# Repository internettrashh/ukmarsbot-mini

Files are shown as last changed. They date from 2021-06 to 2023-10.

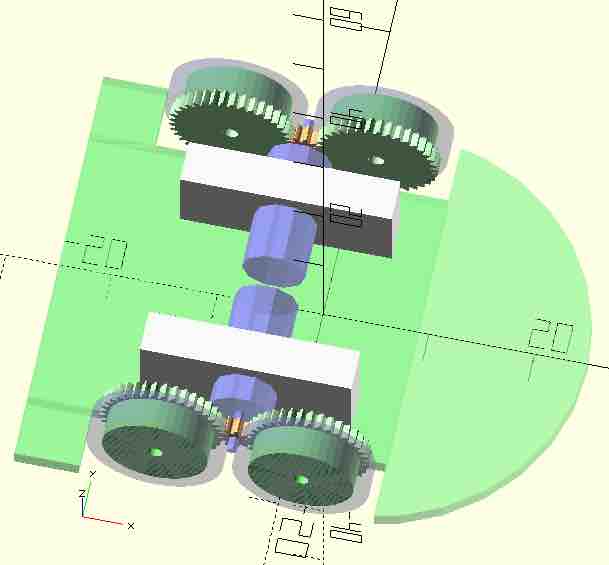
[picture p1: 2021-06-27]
half-size-mech-prototypes/prototype1.jpg

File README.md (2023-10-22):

# ukmarsbot-mini
A half size micromouse project

Over time, this will grow into a fully described project for an open source, half-sized micromouse designed by members of the UK Micromouse and Robotics Society (UKMARS).

The project will include full hardware details and demonstration software that will provide all the basic functions needed to run the robot in a contest maze.

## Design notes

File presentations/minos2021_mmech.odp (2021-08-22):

## 4 wheel concept

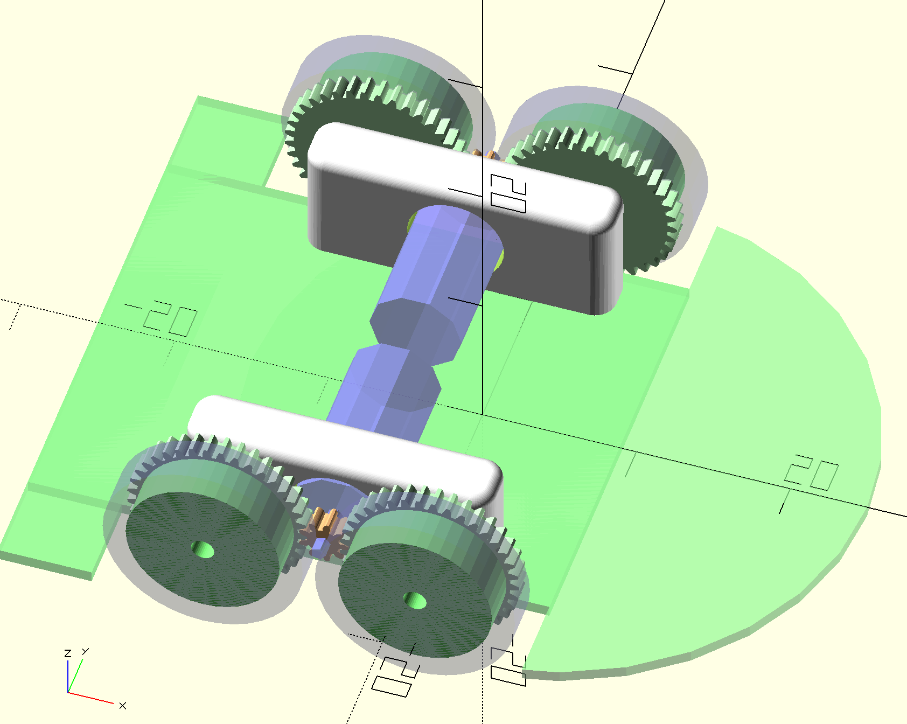
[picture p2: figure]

## Size against ukmarsbot

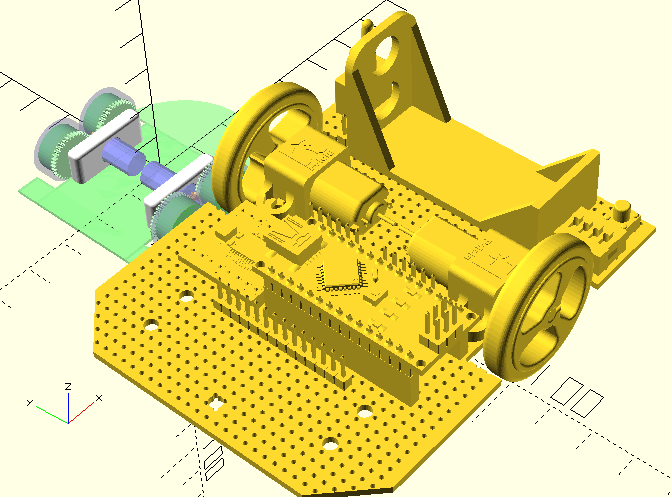
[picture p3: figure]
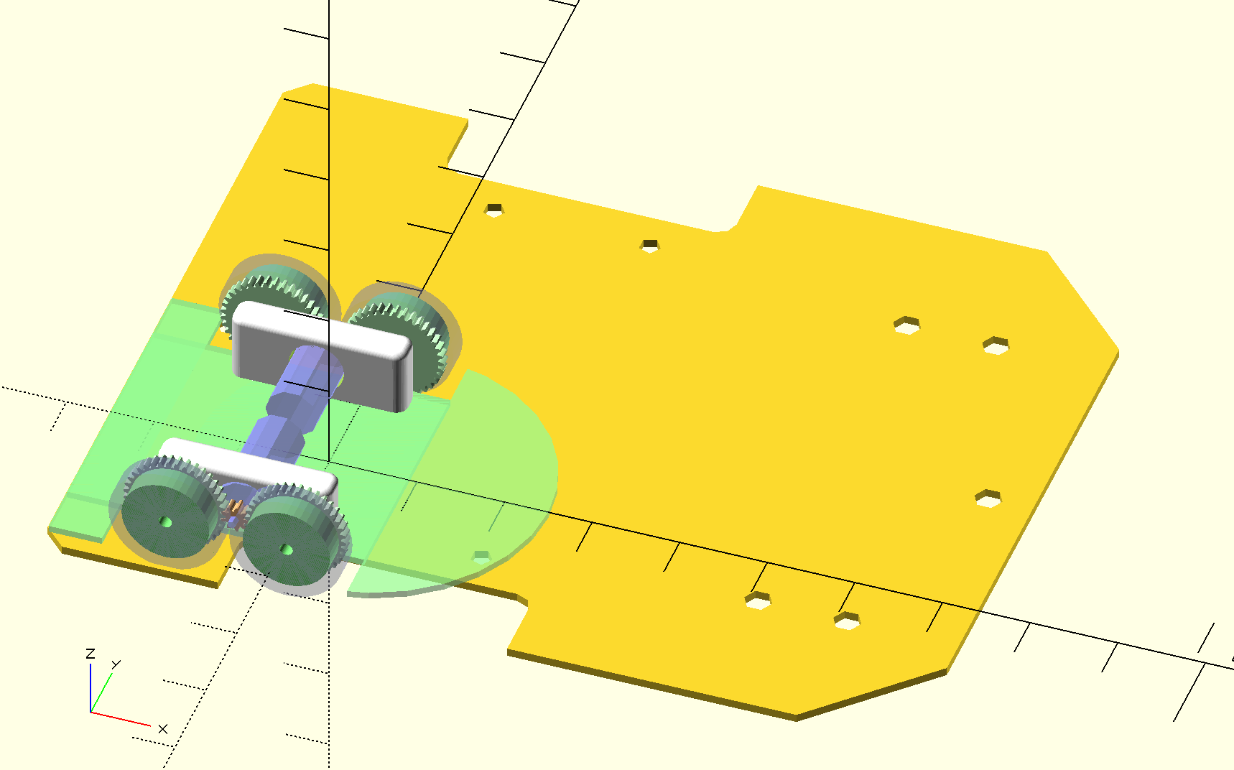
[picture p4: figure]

## 4 wheel concept

Potential Problems

Wheels need to be 0.3 module – basically custom gears/wheels (supply) … and tyre availability.

## Wheels

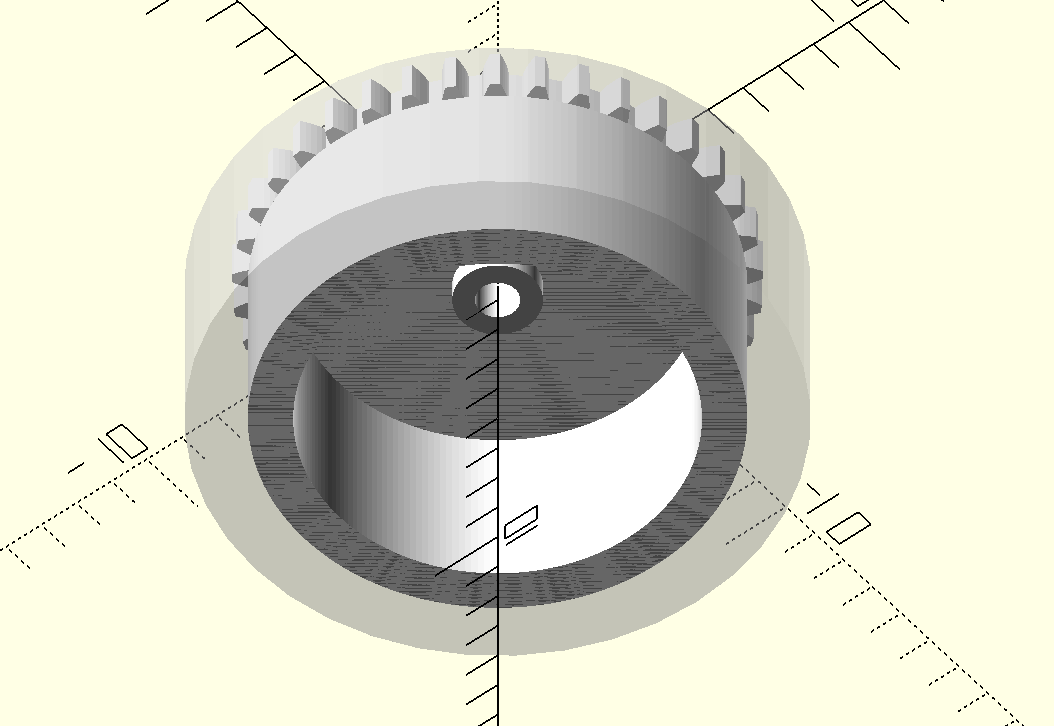
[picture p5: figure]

Holes in rear face?

## Two wheels from same PCB?

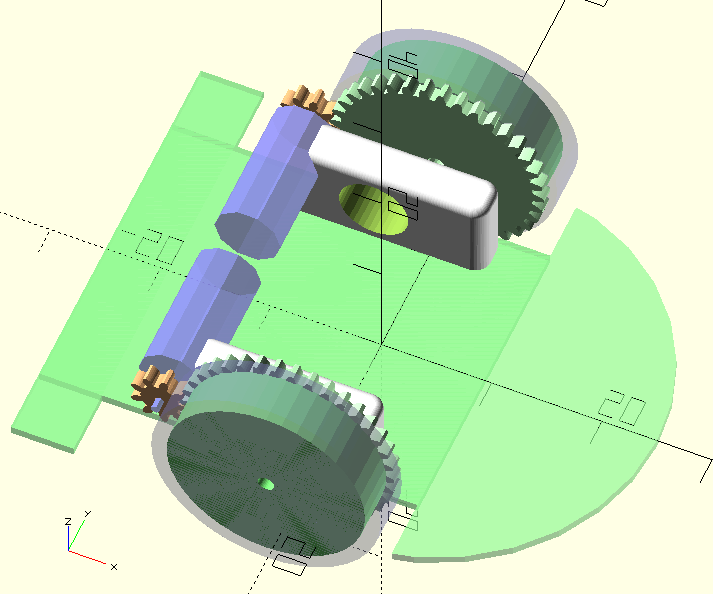
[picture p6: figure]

Maybe wheels could be standard 0.5 mod gear attached to wheel?

Potential Problems

Encoder position not the same

Extra motor keep outs PCB

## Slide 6

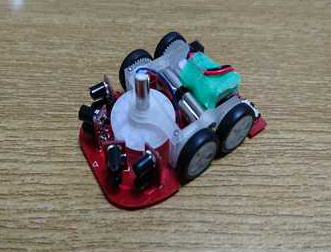
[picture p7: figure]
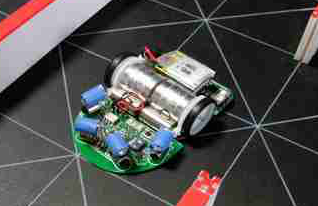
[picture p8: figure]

RTCorp

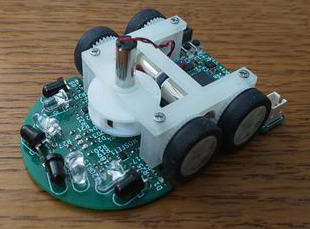
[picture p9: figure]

tennisyi mouse

Early BeeClone?

  Matsui’s Sapphire

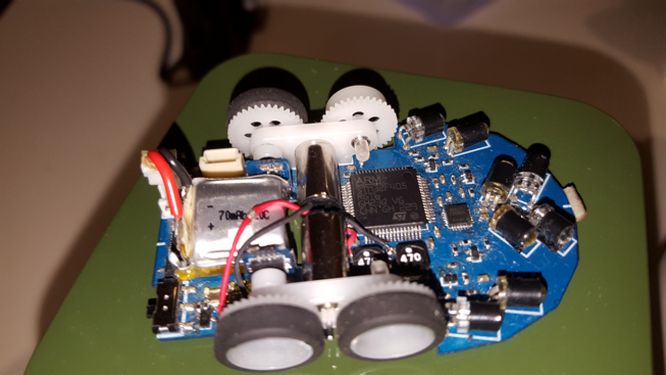
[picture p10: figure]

  Matsui’s Zirconia (open design)

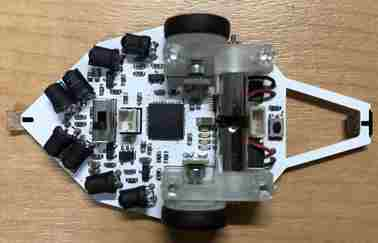
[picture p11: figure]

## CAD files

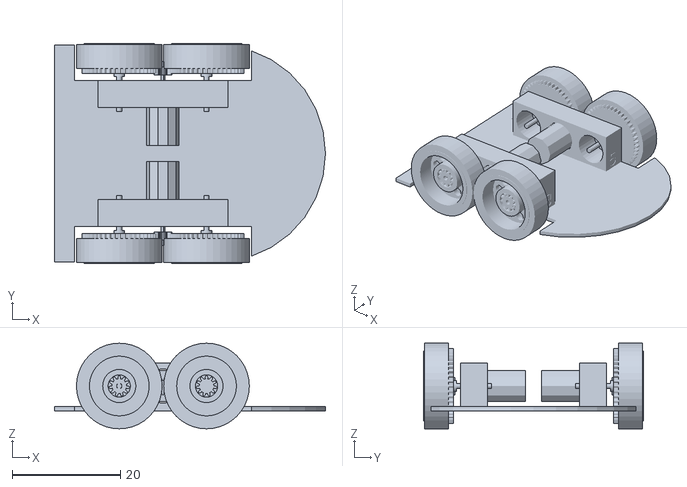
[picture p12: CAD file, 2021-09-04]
half-size-mech-prototypes/output_files/prototype2v5_full.stl
50.0 x 40.5 x 15.8

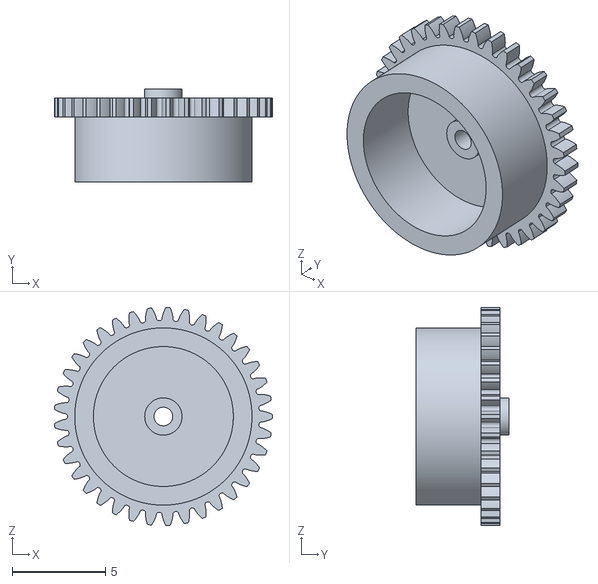
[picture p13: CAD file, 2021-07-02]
half-size-mech-prototypes/zirconia_single_wheel_rim.stl
11.7 x 5.00 x 11.7

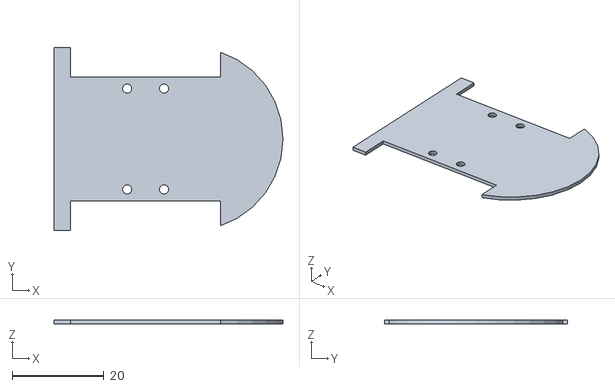
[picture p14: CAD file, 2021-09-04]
half-size-mech-prototypes/output_files/prototype2v5_pcb_no_heads.stl
50.0 x 40.0 x 0.8

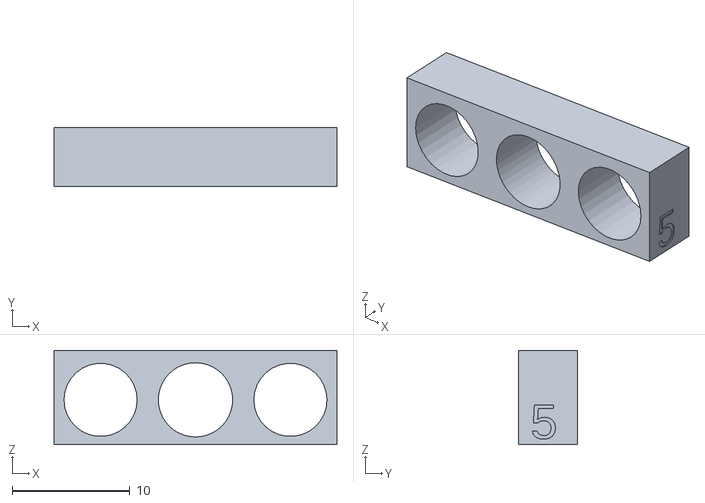
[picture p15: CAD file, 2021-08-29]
half-size-mech-prototypes/output_files/prototype2_mount_v5.stl
24.0 x 5.00 x 8.00

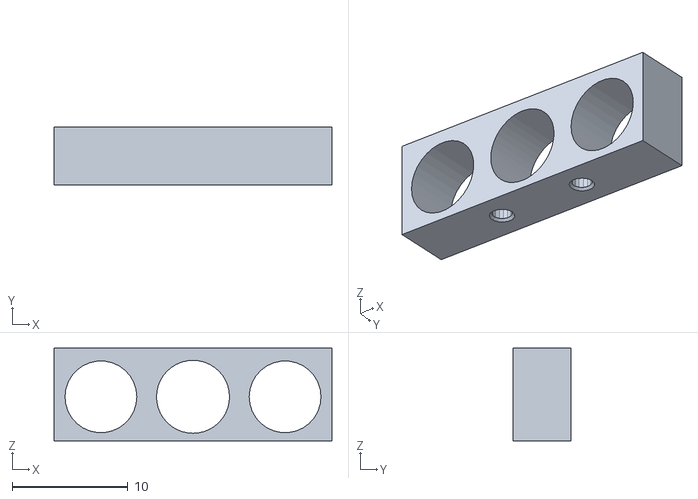
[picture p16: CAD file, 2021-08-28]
half-size-mech-prototypes/output_files/prototype2_v4_bearing0.2.stl
24.0 x 5.00 x 8.00

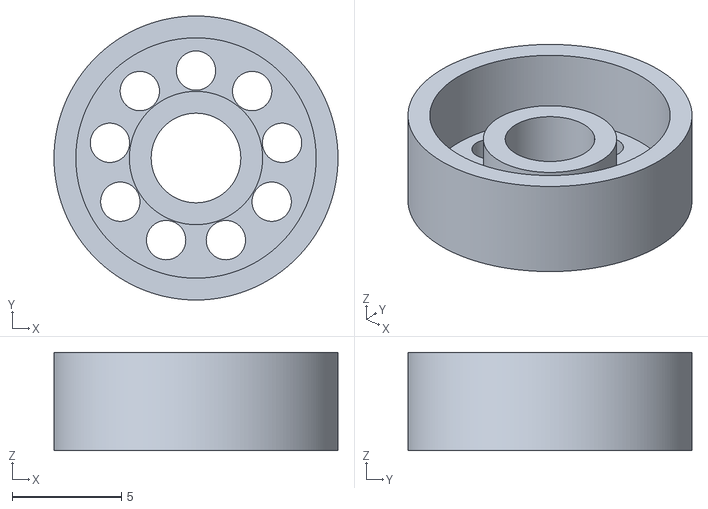
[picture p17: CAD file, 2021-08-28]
half-size-mech-prototypes/output_files/prototype_v4_wheel_hub.stl
13.0 x 13.0 x 4.50

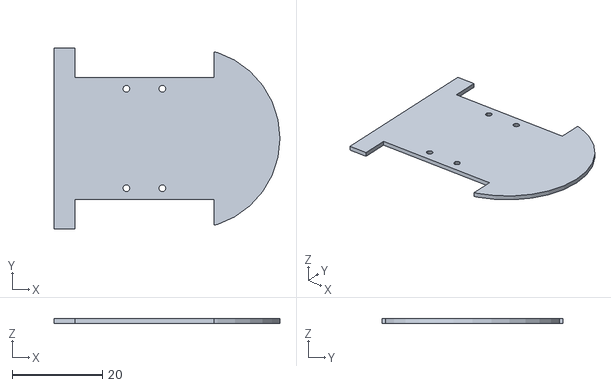
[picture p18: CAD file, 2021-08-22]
half-size-mech-prototypes/output_files/prototype2_pcb_v2_1mm_thick.stl
50.0 x 40.0 x 1.00

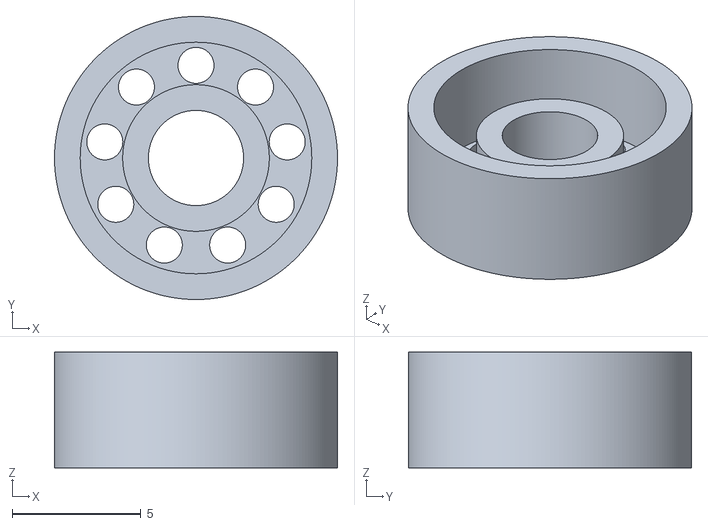
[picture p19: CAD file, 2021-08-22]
half-size-mech-prototypes/output_files/prototype2_wheel_hub.stl
11.0 x 11.0 x 4.50

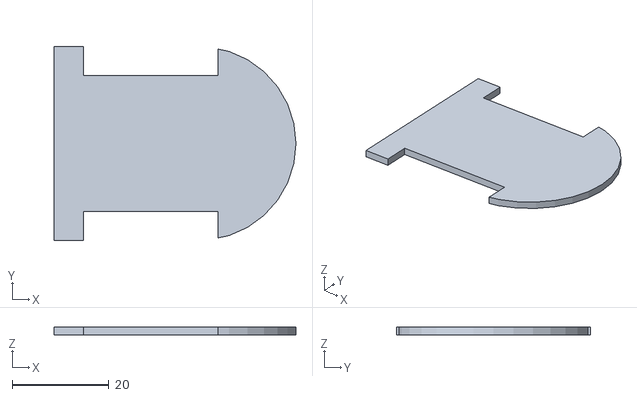
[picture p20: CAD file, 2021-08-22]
half-size-mech-prototypes/output_files/prototype1_pcb28June2021.stl
50.0 x 40.0 x 1.60

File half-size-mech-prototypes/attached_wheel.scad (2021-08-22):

// Simple Micromouse wheel that uses a 0.3 Mod 44:11 gear plugged into it
//
use <pd-gears/pd-gears.scad>

show_tyre = true;
show_gear = true;
show_wheel = true;
enable_holes_in_gear = true;    // Currently hardcoded, not calculated based on size.

faces = 200;
//faces = 50;

epsilon = 0.001;        // small constant to avoid coincident walls on union, difference or intersection


function module_to_circular_pitch(module_val) = module_val * PI;


// mini_UKMARS constants
// =====================
type_expansion = 2;     // expand rhe rim and tyre to we don't run on the gear teeth
m_RIM_depth = 4.5;
m_RIM_outside_radius = (11+type_expansion)/2;
m_RIM_inside_radius = m_RIM_outside_radius-1;
RIM_back_depth = 1;

// this is the gear that fits onto the wheel
m_gear_thickness = 1;
m_gear_teeth = 44;
m_gear_module = 0.3;
m_axle_collar_length = 0.3;
m_axle_collar_diameter = 4;
m_subgear_thickness = 4.55 - (m_gear_thickness + m_axle_collar_length);
m_subgear_teeth = 11;
m_axle_diameter = 1.5;        // usually this is smaller, but we widen to 2mm
m_gear_offset = m_axle_collar_length;

m_tyre_OD = 13.8+type_expansion;
m_tyre_thickness = m_tyre_OD/2 - m_RIM_outside_radius;

// common constants
defined_pressure_angle = 20;

// gear holder
RIM_gear_holder_depth = m_subgear_thickness;
RIM_gear_holder_thickness = 1;
gear_pinch_radius = -0.2;       // negative = give it a bit of extra clearence, positive = make it tighter
RIM_gear_holder_inside_radius = outer_radius(module_to_circular_pitch(m_gear_module), m_subgear_teeth) - gear_pinch_radius;
RIM_gear_holder_outside_radius = RIM_gear_holder_inside_radius + 1;


//////////////////////////////////////////////////////////////////////////////////////////////
//             ____                          
//  ___  ___  / ___\   ____  _____  _______  
//  \  \/  / / /_/  >_/ __ \ \__  \ \_  __ \ 
//   >    <  \___  / \  ___/  / __ \_|  | \/ 
//  /__/\_ \/_____/   \___  >(____  /|__|    
//        \/              \/      \/         
//   
// Saves generating full gears when prototyping
//////////////////////////////////////////////////////////////////////////////////////////////
replace_cylinder = false;
cylinder_segments = 100;

module xgear(mm_per_tooth, teeth, thickness, hole_diameter, center = false)
{
    if (replace_cylinder) {
        difference() {
            cylinder(thickness, outer_radius(mm_per_tooth, teeth, 0), outer_radius(mm_per_tooth, teeth, 0), center, $fn = cylinder_segments);
        translate([0,0, (center ? 0 : -0.1)])
            cylinder(h=thickness+0.2, r=hole_diameter/2, center=center, $fn=cylinder_segments);
        }
    }
    else
        gear(mm_per_tooth, teeth, thickness, hole_diameter, center, pressure_angle = defined_pressure_angle);
}

//////////////////////////////////////////////////////////////////////////////////////////////
//
// make wheels lighter
//


module hole_circles(RIM_depth, gear_thickness, gear_offset) {
    number_of_circles = 9;
    hole_size = 0.9;
    hole_depth = 1 + RIM_depth + gear_thickness + gear_offset;
    hole_orbit_radius = 3.8-gear_pinch_radius;
    hole_faces = 50;
    
    for(i = [0 : number_of_circles]) {
        rotate([0, 0, i * (360 / number_of_circles)]) translate([0, hole_orbit_radius, 0])
            cylinder(hole_depth, hole_size, hole_size, $fn=hole_faces);
    }
}

//////////////////////////////////////////////////////////////////////////////////////////////
//
// zwheel
//
module simple_wheel(RIM_depth, gear_thickness, gear_offset, RIM_outside_radius, RIM_inside_radius, axle_collar_diameter, axle_collar_length, axle_diameter, gear_teeth, gear_module)
{
    /*color("white", 1.0) */ {
        difference() {
            union() {
                if(show_wheel) /*color("yellow", 1.0)*/ {
                    // main RIM
                    translate([0, 0, gear_thickness+gear_offset]) { 
                        difference() {
                            cylinder(RIM_depth, RIM_outside_radius, RIM_outside_radius, $fn=faces);
                            translate([0,0,-0.05]) cylinder(RIM_depth+0.1, RIM_inside_radius, RIM_inside_radius, $fn=faces);
                        }
                        // RIM back
                        cylinder(RIM_back_depth, RIM_outside_radius, RIM_outside_radius, $fn=faces);
                        // Gear holder on RIM
                        difference() {
                            cylinder(RIM_gear_holder_depth, RIM_gear_holder_outside_radius, RIM_gear_holder_outside_radius, $fn=faces);
                            translate([0,0,-0.05-RIM_gear_holder_thickness]) cylinder(RIM_gear_holder_thickness+RIM_gear_holder_depth+0.1, RIM_gear_holder_inside_radius, RIM_gear_holder_inside_radius, $fn=faces);
                        }
                        
                    }
                }
            }
            union() {
                // axle  actually as wide as gear holder
                //translate([0, 0, -RIM_depth/2]) cylinder(RIM_depth*2, axle_diameter/2, axle_diameter/2, $fn=faces);
                translate([0, 0, -RIM_depth/2]) cylinder(RIM_depth*2, RIM_gear_holder_inside_radius, RIM_gear_holder_inside_radius, $fn=faces);

                if(enable_holes_in_gear) {
                    hole_circles(RIM_depth, gear_thickness, gear_offset);
                }
            }
            
        }
        
        if(show_gear) color("white", 1.0) difference() { 
            union() {
            // axel collar
            cylinder(axle_collar_length, axle_collar_diameter/2, axle_collar_diameter/2, $fn=faces);
            translate([0,0,gear_offset-epsilon]) xgear(module_to_circular_pitch(gear_module), gear_teeth, gear_thickness, axle_diameter, center=true);
            translate([0,0,gear_offset+gear_thickness-epsilon*2]) xgear(module_to_circular_pitch(gear_module), m_subgear_teeth, m_subgear_thickness, axle_diameter, center=true);
            }
            // axle for gear
            translate([0, 0, -RIM_depth/2]) cylinder(RIM_depth*2, axle_diameter/2, axle_diameter/2, $fn=faces);
            
        }


    }
}
//////////////////////////////////////////////////////////////////////////////////////////////

module simple_tyre_core(diameter, thickness, hole_diameter, center = false)
{
    r = diameter/2;
    difference() {
        cylinder(thickness, r, r, center, $fn = cylinder_segments);
        translate([0, 0, (center ? 0 : -0.1)])
            cylinder(h=thickness+0.2, r=hole_diameter/2, center=center, $fn=cylinder_segments);
    }
}
//////////////////////////////////////////////////////////////////////////////////////////////

module simple_tyre(RIM_outside_radius, RIM_depth, gear_thickness, gear_offset, tyre_thickness)
{
    wheel_diameter = RIM_outside_radius*2;
    wheel_thickness = RIM_depth;
    wheel_gear_thickness = -(RIM_depth+gear_thickness+gear_offset);

    angle=0; offset=0; offsety=0;
    rotate([0, angle, 0]) translate([offset,  offsety, 0])
        rotate([90,90,0]) 
            {
            translate([0,0,wheel_gear_thickness-epsilon]) color([0.3, 0.3, 0.3, 0.5]) simple_tyre_core(wheel_diameter+2*tyre_thickness, wheel_thickness-epsilon*2, wheel_diameter, center = false);
            }
}
//
//
//


simple_wheel(m_RIM_depth, m_gear_thickness, m_gear_offset, m_RIM_outside_radius, m_RIM_inside_radius, m_axle_collar_diameter, m_axle_collar_length, m_axle_diameter, m_gear_teeth, m_gear_module);


if(m_tyre_thickness != 0 && show_tyre)
{
    rotate([90,0,0]) simple_tyre(m_RIM_outside_radius, m_RIM_depth, m_gear_thickness, m_gear_offset, m_tyre_thickness);
}

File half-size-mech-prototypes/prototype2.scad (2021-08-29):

// Micromouse wheel & gear train

use <pd-gears/pd-gears.scad>
use <attached_wheel.scad>

/* TODO
   	•	It may be convenient at some point to have the drawing x origin at the motor axle position. (Maybe rather than recalculating everything I'll just put an option in the top of the file (so we can have PCB view and motor view).)
	•	PCB to gear spacing (looks like we could get another 1-2 mm of PCB there.)
	•	Motor hole tuning (after print)
	•	Decide on wheel axle width (what is wheel axle hole in mount, e.g. bearing diameter, or whatever)
    •	Tyre sizes? Tyres need to be bigger than wheel gears.

*/

//
// What things to render
//
// (select one of these only)
render_whole_mouse = true;                                         
render_gears_only = false;       // at the moment render hub only from attached_wheel.scad
render_pcb_only = false;
render_mount_only = false;
export_pcb = false;

// options
number_of_wheels = 4;       // @TODO: wheels=2 requires some work
enable_tyres = true;
basic_wheels = true;
rounded_motor_holder = false;
hide_wheels_and_motor = false; // option for render_whole_mouse only
SHOW_SCREW_DEPTH = false;   // ensure false in real print
hide_one_wheel_pair = true;
disable_screw_heads = false;

// helper
function module_to_circular_pitch(module_val) = module_val * PI;

// To show comparative size to classic Micromouse
//translate([-26, -20, -3]) import("ukmarsbot.dxf");
//translate([10, -62, 6.5]) rotate([0,0,90]) import("ukmarsbot-a v47.stl");

epsilon = 0.001;        // small constant to avoid coincident walls on union, difference or intersection


//////////////////////////////////////////////////////////////////////////////////////////////
//        .__                          
//  ______|__|________  ____    ______ 
// /  ___/|  |\___   /_/ __ \  /  ___/ 
// \___ \ |  | /    / \  ___/  \___ \  
///____  >|__|/_____ \ \___  >/____  > 
//     \/           \/     \/      \/  
//     
//////////////////////////////////////////////////////////////////////////////////////////////

board_length = 50;
board_width_min = 27;
board_width_max = 40;
board_thickness = 0.8;

motor_body_length = 12;
motor_body_diameter = 6;
motor_shaft_protrude_length = 3.5;
motor_shaft_diameter = 0.8;

motor_separation = 3;

// gear definitions
// Ratio 37:9 (no coprime) - 4.111
module_value_4wheel = 0.3;
module_value_2wheel = 0.5;
//module_value = (number_of_wheels==4) ? module_value_4wheel : module_value_2wheel;
module_value = module_value_4wheel;

// motor gear definitions
motor_gear_teeth = 9;
motor_gear_mm_per_tooth = module_to_circular_pitch(module_value);
motor_gear_mm_per_tooth_2w = module_to_circular_pitch(module_value_2wheel);
motor_gear_hole = 0.8;
motor_gear_thickness = 1.5;
motor_gear_outside_radius = outer_radius(motor_gear_mm_per_tooth, motor_gear_teeth, 0);

// other wheel specific items
wheel_shaft_diameter = 1;         // these are the shaft diameters for Rob's axles
//wheel_shaft_diameter = 2.2;       // Size for M2 screws???
wheel_shaft_length = 10;

// wheel gear sizes
wheel_gear_teeth = 44;
wheel_gear_mm_per_tooth = module_to_circular_pitch(module_value);
wheel_gear_thickness = 1;
type_expansion = 2;     // expand rhe rim and tyre to we don't run on the gear teeth
wheel_diameter = (11+type_expansion);
wheel_diameter_2w = 18;
//wheel_diameter = (number_of_wheels==4) ? wheel_diameter_4w : wheel_diameter_2w;

wheel_thickness = 4.5;
//wheel_hole = wheel_thickness-wheel_gear_thickness;
wheel_hole = wheel_shaft_diameter;
tyre_thickness = 1.4;

// axle holder sizes
holder_height = 8;
holder_width = 5;
holder_length = 24;
holder_separation = 8.5;

// Screw details (M2*4 countersunk head, self-tapping, nickel-plated steel, flat head, metric)
// Using longer M2 screws would be problematic, but potentially we could use M1.7*6 or M1.4*5. 
mount_holder_screw_diameter_grip = 1.6;     // OD = 2, but we need something for the threads to grip
mount_holder_screw_diameter_OD = 2;
mount_holder_screw_total_depth = 3.8;       // including head, actual total = 3.65mm plus some clearance
mount_holder_screw_head_diameter = 3.7;     // 3.65mm actual, 0.05 clearance
mount_holder_screw_head_depth = 1;
mount_holder_screw_depth = mount_holder_screw_total_depth-mount_holder_screw_head_depth;               // excluding head
mount_holder_screw_faces = 15;

// general positions
motor_sets_backwards_offset_4w = 5;
motor_sets_backwards_offset_2w = 13;
motor_sets_backwards_offset = motor_sets_backwards_offset_4w;
wheel_to_board_edge_extra_clearance = 0.5;

motor_rise_4w = 0.8;
motor_rise_2w = 2.8;
motor_rise = (number_of_wheels==4) ? motor_rise_4w : motor_rise_2w;

//
// Gear dimensions
//
motor_PR = pitch_radius(motor_gear_mm_per_tooth, motor_gear_teeth);
motor_gear_OD = 2*outer_radius(motor_gear_mm_per_tooth, motor_gear_teeth, 0);
echo(str("Motor gear outside diameter = ", motor_gear_OD, "mm"));

wheel_gear_PR = pitch_radius(wheel_gear_mm_per_tooth, wheel_gear_teeth);
wheel_gear_OD = 2*outer_radius(wheel_gear_mm_per_tooth, wheel_gear_teeth, 0);
echo(str("Wheel Gear large outside diameter = ", wheel_gear_OD, "mm"));
wheel_tyre_OD = wheel_diameter+2*tyre_thickness;
motor_to_4wheel_centers = wheel_gear_PR+motor_PR+0.1;

// additive sizes - board calculations
motor_to_board_clearance = (wheel_tyre_OD/2 + wheel_gear_PR + motor_PR + wheel_to_board_edge_extra_clearance);
//echo(str(board_length/2," ",motor_to_board_clearance));


// board tail calculations
board_tail_length = (board_length/2)-motor_to_board_clearance-motor_sets_backwards_offset_4w;
enable_board_tail = board_tail_length >= 3;

// front calculations
in_front_of_wheels_board_position = motor_to_board_clearance-motor_sets_backwards_offset_4w;


//
// some calculations for the 2 wheel variant
//
motor_PR_2w = pitch_radius(motor_gear_mm_per_tooth_2w, motor_gear_teeth);
wheel_gear_PR_2w = pitch_radius(motor_gear_mm_per_tooth_2w, wheel_gear_teeth);

// Bearing
// MR62ZZ (2x6x2.5mm) 
bearing_OD = 6+0.2; // 0.2 is clearance, 0.1 is too tight, 0.2 is a bit loose (but you can glue it)
bearing_ID = 2;
bearing_thickness = 2.5;


//////////////////////////////////////////////////////////////////////////////////////////////
//                                    .___             ___.             
// _______   ____   __ __   ____    __| _/ ____   __ __\_ |__    ____   
// \_  __ \ /  _ \ |  |  \ /    \  / __ |_/ ___\ |  |  \| __ \ _/ __ \  
//  |  | \/(  <_> )|  |  /|   |  \/ /_/ |\  \___ |  |  /| \_\ \\  ___/  
//  |__|    \____/ |____/ |___|  /\____ | \___  >|____/ |___  / \___  > 
//                             \/      \/     \/            \/      \/  
//////////////////////////////////////////////////////////////////////////////////////////////

module torus(r1, r2)
{
    rotate_extrude(convexity = 10, $fn=50)
    translate([r2, 0, 0])
    circle(r = r1, $fn = 50);
}

module roundcube(h, l, w, side_r, top_r)
{
    //difference()
    {
        hull()
        {
            fn_cylinder=30;
            translate([side_r,side_r,0]) cylinder(0.05, side_r, side_r, $fn=fn_cylinder);
            translate([w-side_r, side_r,0]) cylinder(0.05, side_r, side_r, $fn=fn_cylinder);
            translate([side_r, l-side_r,0]) cylinder(0.05, side_r, side_r, $fn=fn_cylinder);
            translate([w-side_r, l-side_r,0]) cylinder(0.05, side_r, side_r, $fn=fn_cylinder);
            translate([side_r, side_r, h-top_r]) torus(top_r, side_r-top_r);
            translate([w-side_r, side_r, h-top_r]) torus(top_r, side_r-top_r);
            translate([side_r, l-side_r, h-top_r]) torus(top_r, side_r-top_r);
            translate([w-side_r, l-side_r, h-top_r]) torus(top_r, side_r-top_r);
        }
    }
}

/*
x_side_r = 7;
x_top_r = 3;
x_h = 11;
x_l = 44;
x_w = 77;
roundcube(x_h, x_l, x_w, x_side_r, x_top_r);
*/

//////////////////////////////////////////////////////////////////////////////////////////////
//             ____                          
//  ___  ___  / ___\   ____  _____  _______  
//  \  \/  / / /_/  >_/ __ \ \__  \ \_  __ \ 
//   >    <  \___  / \  ___/  / __ \_|  | \/ 
//  /__/\_ \/_____/   \___  >(____  /|__|    
//        \/              \/      \/         
//   
// Saves generating full gears when prototyping
//////////////////////////////////////////////////////////////////////////////////////////////
replace_cylinder = false;
cylinder_segments = 40;

module xgear(mm_per_tooth, teeth, thickness, hole_diameter, center = false)
{
    if (replace_cylinder) {
        difference() {
            cylinder(thickness, outer_radius(mm_per_tooth, teeth, 0), outer_radius(mm_per_tooth, teeth, 0), center, $fn = cylinder_segments);
        translate([0,0, (center ? 0 : -0.1)])
            cylinder(h=thickness+0.2, r=hole_diameter/2, center=center, $fn=cylinder_segments);
        }
    }
    else
        gear(mm_per_tooth, teeth, thickness, hole_diameter, center, pressure_angle  = 20);
}
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

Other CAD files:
half-size-mech-prototypes/output_files/prototype2_v4_bearing0.1.stl
half-size-mech-prototypes/output_files/prototype2_v4_pcb_2mmholes.stl
half-size-mech-prototypes/output_files/prototype2_v4_pcb_countersunk.stl
half-size-mech-prototypes/output_files/prototype2_mount_v3.stl
half-size-mech-prototypes/output_files/prototype2_mount_v2.stl
half-size-mech-prototypes/output_files/prototype2_pcb_v2.stl
half-size-mech-prototypes/output_files/prototype2_wheel_hub_v2.stl
half-size-mech-prototypes/output_files/prototype2_pcb.stl
half-size-mech-prototypes/output_files/prototype2_mount.stl
half-size-mech-prototypes/simple_wheels.scad
half-size-mech-prototypes/pd-gears/pd-gears.scad
half-size-mech-prototypes/output_files/gears_prototype1.stl
half-size-mech-prototypes/output_files/prototype1.stl
half-size-mech-prototypes/output_files/prototype1_pcb28June2021.dxf
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

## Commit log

2021-06-27 First sketch - no sizes are correct.
    [pd-gears.scad, prototype1.scad]
2021-06-27 Picture of prototype1
2021-06-27 Adjustments to be closer to real mouse
    [prototype1.scad]
2021-06-27 Add photo of latest prototype
2021-06-27 Render gears as separate element.
    [prototype1.scad]
2021-06-28 add directories for firmware and kicad
2021-06-28 Various improvements after review by Peter.
    [prototype1.scad]
2021-07-02 Simple wheel generator in OpenSCAD.
    [simple_wheels.scad, zirconia_single_wheel_rim.stl]
2021-07-02 Adjust to suggested parameters in Peter’s email.
    [simple_wheels.scad]
2021-07-02 Switch to proposed sizes of wheel.
    [simple_wheels.scad]
2021-07-02 Some 2 wheel, 4 wheel hackery.
    [prototype1.scad]
2021-07-02 Add holes in gear.
    [simple_wheels.scad]
2021-07-03 Added epsilon to avoid preview artefacts due to coincidental walls on tyre/wheel unions
    [prototype1.scad, simple_wheels.scad]
2021-07-20 Modifications based on discussions
    [prototype1.scad, simple_wheels.scad]
2021-08-08 New wheel type using pre-made gear
    [attached_wheel.scad]
2021-08-08 Provisional finished wheel
    [attached_wheel.scad]
2021-08-22 Second prototype
    [attached_wheel.scad, prototype2.scad]
2021-08-22 Added prototype 1 output files.
    [gears_prototype1.stl, prototype1.stl, prototype1_pcb28June2021.dxf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]
2021-08-22 Prototype 2 output.
    [prototype2.scad, prototype2_mount.stl, prototype2_pcb.stl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]
2021-08-22 Moved prototype2 hub to output files.
    [prototype2_wheel_hub.stl]
2021-08-22 Prototype Version 2 changes
    [attached_wheel.scad, prototype2.scad, prototype2_mount_v2.stl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]
2021-08-22 Altered bearing clearance (v3), and created thicker PCB.
    [prototype2.scad, prototype2_mount_v3.stl, prototype2_pcb_v2_1mm_thick.stl]
2021-08-28 Changes for screw in prototype 2 v4. Uses M2*4 countersunk head, self-tapping, nickel-plated steel, flat head, metric.
    [prototype2.scad]
2021-08-28 v4 test
    [prototype2.scad, prototype2_v4_bearing0.1.stl, prototype2_v4_bearing0.2.stl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]
2021-08-29 Prototype 2 v5 (gap between gears increased by 0.1) Clearance for bearing set back to 0.2.
    [prototype2.scad]
2021-08-29 Prototype 2 v5 mount STL
    [prototype2_mount_v5.stl]
2021-08-29 new output file rendering
    [prototype2.scad]
2021-08-29 actual filename of render …
    [prototype2.scad]
2021-09-04 Prototype files added
    [prototype2v5_full.stl, prototype2v5_pcb_no_heads.dxf, prototype2v5_pcb_no_heads.stl]
